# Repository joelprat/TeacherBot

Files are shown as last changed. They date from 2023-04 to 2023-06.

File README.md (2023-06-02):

# TeacherBot

# Table of Contents
  * [What is this?](#what-is-this)
  * [Physical Robot](#physical-robot)
  * [Hardware Scheme](#hardware-scheme)
  * [Software Scheme](#software-scheme)
  * [Requirements](#requirements)
  * [How to use](#how-to-use)
  * [TeacherBot DEMO](#teacherbot-demo)
  * [Authors](#authors)

# What is this?

This project consists of the design and construction of a robot capable of helping you to improve your knowledge of Catalan. It is able to understand and highlight syntax errors. 

It uses different electronic components, such as an Arduino board, stepper motors, motor controllers, a Bluetooth module and a servo motor. In addition, it uses the microphone and speaker of a mobile device to generate a human-robot interaction that provides a more dynamic experience. The physical implementation of the robot includes a metal structure and a robotic arm. 

This Catalan teaching robot is a great tool for anyone who wants to improve their Catalan language skills, whether to learn the language for academic or professional purposes, or just for fun. It is easy to use and very effective, which means that you will be able to significantly improve your level of Catalan in a very short time.

# Physical Robot
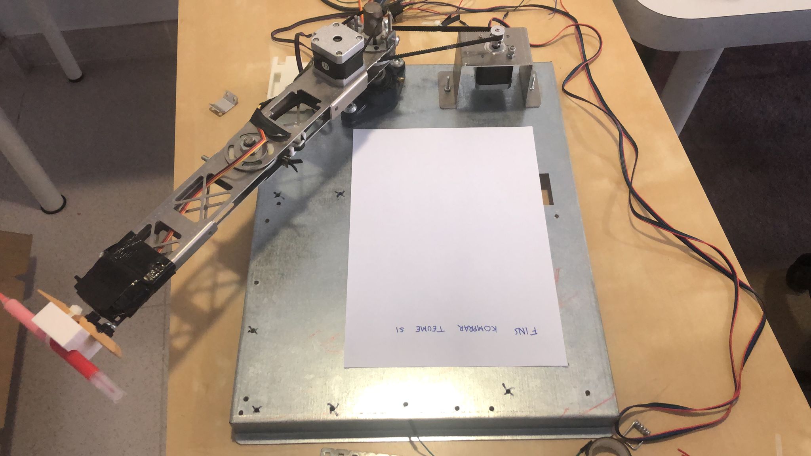
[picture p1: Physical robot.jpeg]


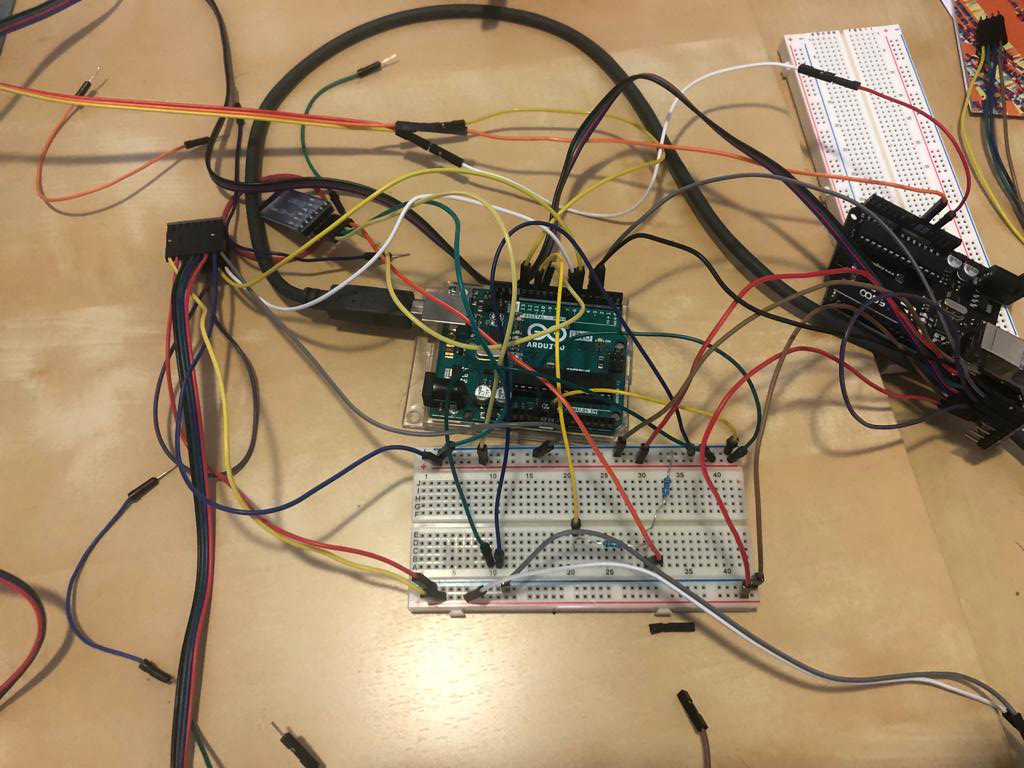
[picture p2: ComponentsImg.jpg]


# Hardware Scheme
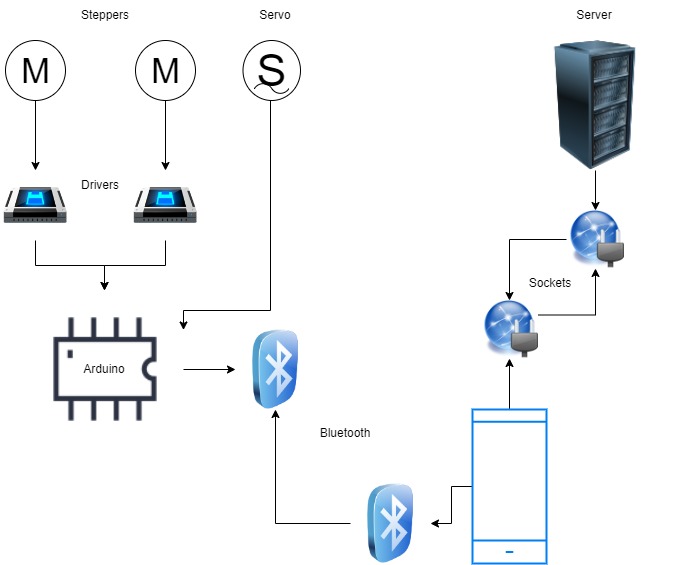
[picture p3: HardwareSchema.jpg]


# Software Scheme
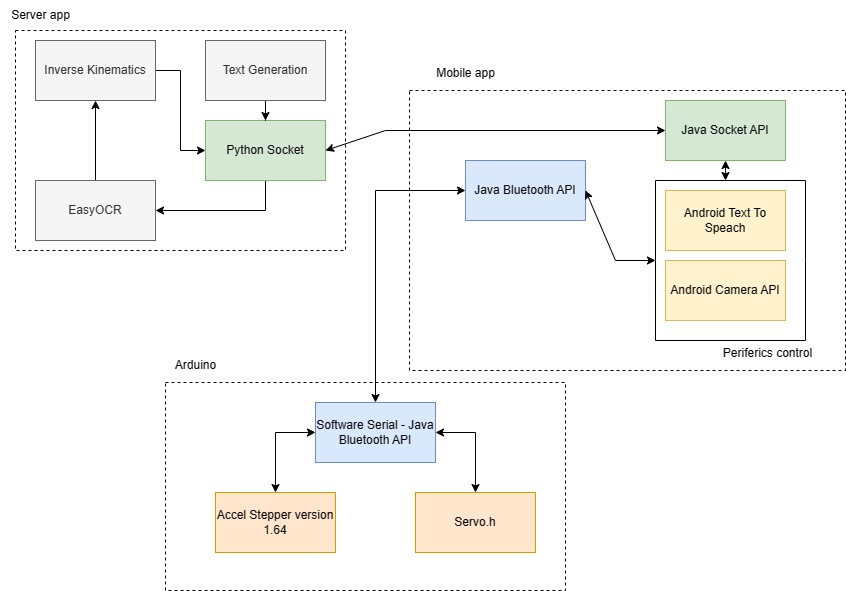
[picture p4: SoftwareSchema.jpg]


# Requirements

Python
 - [Python 3.11.x](https://www.python.org/)
 - [NumPy](https://numpy.org/)
 - [Sympy](https://www.sympy.org/)
 - [sympy.physics.mechanics](https://docs.sympy.org/latest/modules/physics/mechanics/index.html)
 - [requests](https://pypi.org/project/requests/)
 - [easyOCR](https://pypi.org/project/easyocr/)
 - [cv2](https://pypi.org/project/opencv-python/)
 - [socket](https://docs.python.org/3/library/socket.html)
 - [base64](https://docs.python.org/es/3/library/base64.html)
 - [translate](https://pypi.org/project/translate/)
 - [gTTs](https://pypi.org/project/gTTS/)
 - [pillow](https://pypi.org/project/Pillow/)
 - [faker](https://pypi.org/project/Faker/0.7.4/)

[Android Studio JDK](https://developer.android.com/studio):
 - SDK min 24 target 33
 - Java version 1.8
 - Java Bluetooth API
 - Java Socket API
 - Android Text To Speach
 - Android Camera API

[Arduino](https://support.arduino.cc/hc/en-us/articles/360019833020-Download-and-install-Arduino-IDE):
 - Accel Stepper version 1.64 (to be installed in arduino IDE)
 - Software Serial ((included in arduino IDE))
 - Servo.h (included in arduino IDE)
 - String.h (included in arduino IDE)

# How to use

1. Install Python.

2. Clone this repo.

    ```
    $ git clone https://github.com/joelprat/TeacherBot.git
    ```
    
3. Install the required libraries.

   If using Windows:
   
     ```
     $ cd \TeacherBot\algorithms\OCR\
     $ install_dependencies_windows.bat
     ```
     
   If using bash:
   
    ```
    $ cd /TeacherBot/algorithms/OCR/
    $ chmod +x install_dependencies_bash.sh
    $ ./install_dependencies_bash.sh
    ```

4.  Server execution.

    ```
    $ python server.py
    ```

# TeacherBot DEMO

(https://www.youtube.com/watch?v=jaYQ3ElwnmU)

# Authors

- [Contributors](https://github.com/joelprat/TeacherBot/graphs/contributors)

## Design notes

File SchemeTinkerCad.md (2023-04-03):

# Esquema



# Descripción
El diseño del circuito que hemos realizado está compuesto por los siguientes componentes: 
- Una placa arduino UNO R3
- Una placa de pruebas
- Un microservomotor
- Una pantalla LCD 16x2
- Dos motores CC con codificador
- Una controladora de motor (Pololu en el caso de tinkercad debido a la ausencia de nuestra específica controladora de motor). 
- Una pila (Únicamente utilizado para dar funcionamiento en el tinkercad, en nuestro sistema proporcionaremos la potencia por USB).

Otros componentes que no se ven representados en el diseño del circuito ,debido a que no aparecen en la herramienta de tinkercad, són los siguientes: 
- Un altavoz.
- Un microfono.
- Un dispositivo movil para la recaptación de la información a traves de fotografía.
- Un controlador WiFi.
- Un regulador de voltaje para el motor NEMA.

A pesar de no utilizar estos componentes en el diseño realizado, proporcionamos los módulos software para cada uno de los componentes, independientemente de si se encuentran en tinkercad o no, para hacerlos funcionar.

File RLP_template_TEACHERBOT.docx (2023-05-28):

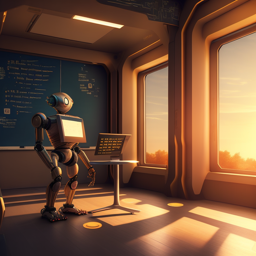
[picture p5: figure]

# TEACHERBOT

TEACHERBOT is a Catalan teacher who will correct texts written by you or dictated by the robot itself.

PROJECT SPRINT #2.
DATE: 03 May 2017

Carles Costas Mateu
Marc Cives Trillo
Joel Prat Vilanova
Eric Caballer Jiménez

TEACHERBOT

TEACHERBOT is a Catalan teacher who will correct texts written by you or dictated by the robot itself.

# Project description

This robot is a Catalan teacher designed to help you improve your Catalan skills. It is able to understand and highlight syntax errors with great accuracy.

This Catalan teacher robot not only corrects your written texts, but also gives you feedback on your mistakes using a screen, to help you understand why you made the mistake and how to avoid it in the future. Also, it can spell you a brief text in order to write it by yourself and then the robot will correct the mistakes that you have done.

This Catalan teaching robot is an excellent tool for anyone who wants to improve their Catalan skills, whether they are learning the language for academic or professional purposes, or just for fun. It's easy to use and very effective, which means you'll be able to significantly improve your Catalan level in no time.

# Electronic components

This is the list of the proposed components:

- 1 x ARDUINO UNO REV.3
- 1 x PROTOBOARD
- 2 x STEPPER MOTOR
- 1 x SERVOMOTOR
- 1 x MICROPHONE
- 1 x SPEAKER
- 1 x WIFI-MODULE
- 1 x ENGINE CONTROLLER
- 1 x VOLTAGE REGULATOR
- 1 x LCD SCREEN

# Hardware Scheme (optional, in case that you already had this ready)

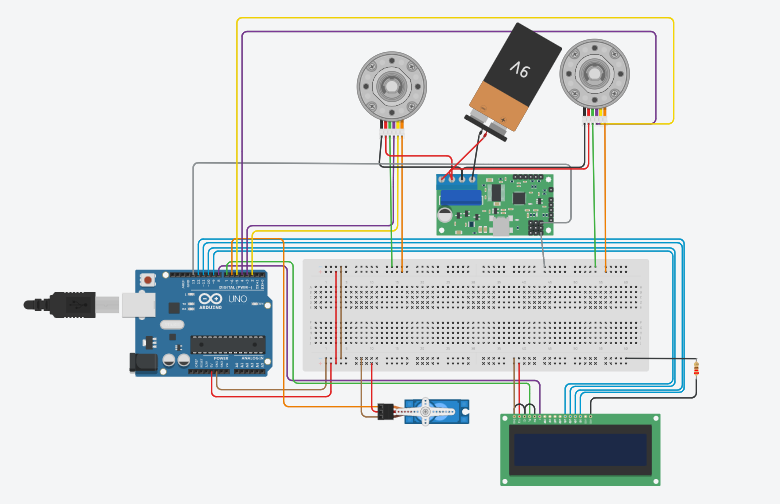
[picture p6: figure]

# Software Architecture (COMPULSORY)

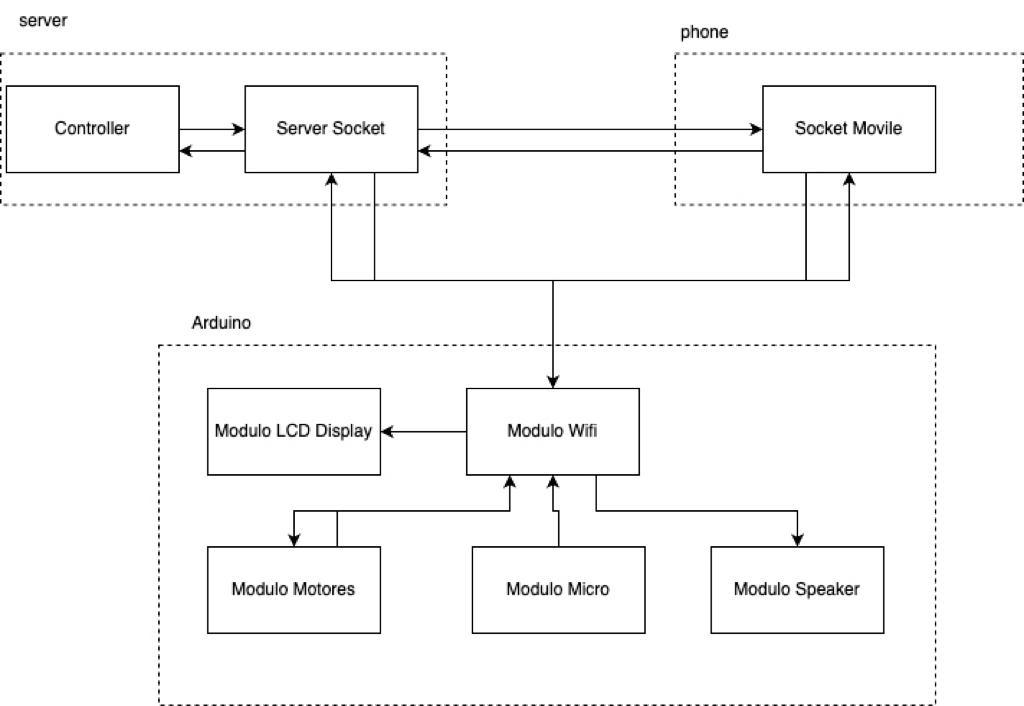
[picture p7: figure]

2) In the diagram, there are three different blocks that correspond to different systems, including the server, the phone, and the Arduino board.  Within the server, there is a block that is responsible for all the logic to compute the OCR and interpret the human speech, as well as generate the sound to be played by the speaker. This module will communicate via UDP socket.  Secondly, we have the phone, where we should have only one socket to receive the order to take photos and send these photos to the central server.  Finally, on the Arduino we have the WiFi module that will communicate with the sockets via UDP to send information from its peripherals or receive information that some of its peripherals need to use.

# Amazing contributions (COMPULSORY)

1. Special focus on Catalan: The robot has been specially designed for learning and improving the Catalan language. This makes it a highly specialized and effective tool for anyone who wants to improve their Catalan language skills.
2. Text correction capability: The robot is able to highlight mistakes in Catalan with great precision. This includes the correction of syntax errors, which helps to improve the text quality and, ultimately, the language skills.
3. Instant feedback: The robot not only corrects errors, but also provides feedback on the errors made so that users understand the error and know how to avoid it in the future. This helps to improve language skills effectively and efficiently.
4. Advanced technology: The robot is based on advanced natural language processing technology that allows it to understand and produce Catalan texts with great precision and coherence. This makes it an extremely effective tool for improving language skills in Catalan.

In case of fulfilling all the objectives our mark should be a 9 out of 10 because it always can be better. We think that we cover various aspects of engineering, both software and hardware, including machine learning with OCR, human language recognition, network communication protocols, and the use of various peripherals such as motors, LED screens, microphones, loudspeakers, etc.

We are working on the development of a new technology, we deal with the Catalan language and try to give an educational value to the project and integrate it with the Catalan culture. Also, it could be a reproducible and scalable project for different aspects in the educational field.

# Extra components and 3D pieces (COMPULSORY only a number of them, not all of them are compulsory in this sprint)

- 1 x PAPER HOLDER
- 1 x MOTOR SUPPORT
- 2 x MOTOR ARM
- 1 x MOBILE PHONE HOLDER
- 2 x NEMA MOTOR
- 1 x PENCIL HOLDER

PAPER HOLDER: It is used to hold the paper in which the robot will write.

MOTOR SUPPORT: It is used to hold the NEMA motors.

MOTOR ARM: Arm used to write on the sheet, by crossing out the word.

MOBILE PHONE HOLDER: Support in charge of holding the mobile to take photos.

NEMA MOTOR: In charge of moving the motor arms.

PENCIL HOLDER: Support in charge of holding the pencil.

We have a structure with a metal base where we place the paper support. The robotic arm consisting of a base 9.5 cm high and two arms 20 cm long each. At the end we put a servo motor to control the movement of the pen. This robot allows us a wide work space which we will only use a part corresponding to a DIN A4 sheet.

PAPER HOLDER:

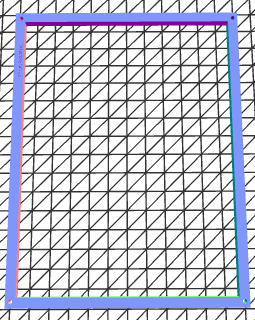
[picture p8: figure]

MOTOR SUPPORT:

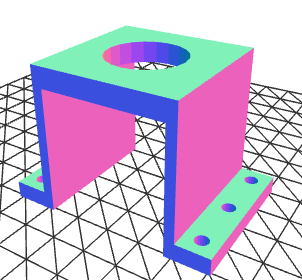
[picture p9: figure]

MOTOR ARM:

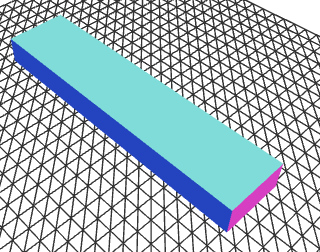
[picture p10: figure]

MOBILE PHONE HOLDER:

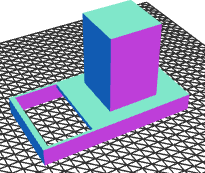
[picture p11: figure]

PENCIL HOLDER:

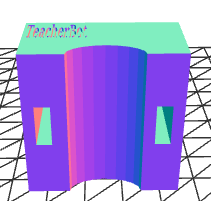
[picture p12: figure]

# Strategy for validation, testing and simulation (COMPULSORY, only the strategy, you do not need the tests to be done yet at this stage)

Functional tests: Functional tests can be performed to verify that the robot is performing its assigned tasks. For example, it can be tested whether the robot is able to accurately detect syntax errors in the Catalan language and provide feedback on the errors.

Integration tests: With these tests we ensure that all parts of the robot work together correctly. For example, we can check that the server communicates correctly with the phone and the Arduino board.

Performance tests: Performance tests can be performed to verify that the robot is working properly and efficiently. For example, it can be checked whether the robot is able to detect a syntax error in a reasonable time and provide feedback.

User evaluation: User tests can be performed to provide feedback on the effectiveness and usability of the robot. This can help identify areas for improvement and make adjustments to better meet user needs.

Risk # | Description | Probability (High/Medium/Low) | Impact (High/Medium/Low) | Contingency plan
1 | Bad recognition of text using OCR | M | H | None
2 | Incompatibility of Catalan with some libraries | M | H | Change the language
3 | Shock of the robotic arm with the support of the mobile support | L | H | Change the structure
4 | Failure with Wifi controller communication | M | H | Use Bluetooth instead
5 | Failure with Bluetooth communication | M | H | None

# Foreseen risks and contingency plan

References

This project has been inspired by the following Internet projects:

AINA: https://www.csuc.cat/es/noticia/aina-el-proyecto-para-que-la-tecnologia-entienda-y-hable-el-catalan

TOURING DRAWING: https://rlpengineeringschooluab2017.wordpress.com/2017/05/30/turing-drawing/

RPL - Computer Engineering. UAB (Barcelona) 2019-2020

Sprint #2 Date: 15 April 2020

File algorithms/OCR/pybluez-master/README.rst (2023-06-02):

==================
 PyBluez
==================

Python extension module allowing access to system Bluetooth resources.

https://github.com/karulis/pybluez

**EXAMPLES:**

.. code-block:: python

    # simple inquiry example
    import bluetooth
    
    nearby_devices = bluetooth.discover_devices(lookup_names=True)
    print("found %d devices" % len(nearby_devices))
    
    for addr, name in nearby_devices:
        print("  %s - %s" % (addr, name))

.. code-block:: python

    # bluetooth low energy scan
    from bluetooth.ble import DiscoveryService

    service = DiscoveryService()
    devices = service.discover(2)

    for address, name in devices.items():
        print("name: {}, address: {}".format(name, address))

*GNU/Linux and Windows XP examples:*

- `examples/simple/inquiry.py`_ - Detecting nearby Bluetooth devices
- `examples/simple/sdp-browse.py`_ - Browsing SDP services on a Bluetooth device.
- `examples/simple/rfcomm-server.py`_ - establishing an RFCOMM connection.
- `examples/simple/rfcomm-client.py`_ - establishing an RFCOMM connection.
- `examples/advanced/read-local-bdaddr.py`_ - provides the local Bluetooth device address.

*GNU/Linux only examples:*

- `examples/simple/l2capserver.py`_
- `examples/simple/l2capclient.py`_
- `examples/simple/asynchronous-inquiry.py`_

- `examples/bluezchat`_
- `examples/advanced/inquiry-with-rssi.py`_
- `examples/advanced/l2-unreliable-server.py`_
- `examples/advanced/l2-unreliable-client.py`_

*GNU/Linux experimental BLE support:*

- `examples/ble/scan.py`_
- `examples/ble/beacon.py`_
- `examples/ble/beacon_scan.py`_
- `examples/ble/read_name.py`_

**CONTACT:**

Please use the mailing list at
    http://groups.google.com/group/pybluez/

**INSTALLATION:**

Use pip(there are also binaries for Windows platform on PyPi):
    
    pip install pybluez

For experimental Bluetooth Low Energy support(only for Linux platform - for additional dependencies please take look at: `ble-dependencies`_):

    pip install pybluez[ble]

For source installation:

    python setup.py install

for Bluetooth Low Energy support:

    pip install -e .[ble]

**BUILD REQUIREMENTS:**

*GNU/Linux:*
 
- Python 2.3 or more recent version
- Python distutils (standard in most Python distros, separate package python-dev in Debian)
- BlueZ libraries and header files

*Windows:*

- Microsoft Windows XP SP1 or Windows Vista/7/8/8.1
- Visual C++ 2010 Express for build for Python 3.3 or newer 
- Visual C++ 2008 Express for build for Python 3.2 or older
- In order to build 64-bit debug and release executables, Visual Studio 2008/2010 Standard Edition is required
- Widcomm BTW development kit 5.0 or later (Optional)
- Python 2.3 or more recent version

*Mac OS X (Unstable - tested only on OS X 10.10/10.11)*:

- Python 2.3 or later
- Xcode
- PyObjc 3.1b or later (https://pythonhosted.org/pyobjc/install.html#manual-installation)

**LICENSE:**

  PyBluez is free software; you can redistribute it and/or modify it under the
  terms of the GNU General Public License as published by the Free Software
  Foundation; either version 2 of the License, or (at your option) any later
  version.
  
  PyBluez is distributed in the hope that it will be useful, but WITHOUT ANY
  WARRANTY; without even the implied warranty of MERCHANTABILITY or FITNESS FOR
  A PARTICULAR PURPOSE. See the GNU General Public License for more details.
  
  You should have received a copy of the GNU General Public License along with
  PyBluez; if not, write to the Free Software Foundation, Inc., 51 Franklin St,
  Fifth Floor, Boston, MA  02110-1301  USA
  
.. _examples/simple/inquiry.py: https://github.com/karulis/pybluez/blob/master/examples/simple/inquiry.py
.. _examples/simple/sdp-browse.py: https://github.com/karulis/pybluez/blob/master/examples/simple/sdp-browse.py
.. _examples/simple/rfcomm-server.py: https://github.com/karulis/pybluez/blob/master/examples/simple/rfcomm-server.py
.. _examples/simple/rfcomm-client.py: https://github.com/karulis/pybluez/blob/master/examples/simple/rfcomm-client.py
.. _examples/advanced/read-local-bdaddr.py: https://github.com/karulis/pybluez/blob/master/examples/advanced/read-local-bdaddr.py

.. _examples/simple/l2capserver.py: https://github.com/karulis/pybluez/blob/master/examples/simple/l2capserver.py
.. _examples/simple/l2capclient.py: https://github.com/karulis/pybluez/blob/master/examples/simple/l2capclient.py
.. _examples/simple/asynchronous-inquiry.py: https://github.com/karulis/pybluez/blob/master/examples/simple/asynchronous-inquiry.py

.. _examples/bluezchat: https://github.com/karulis/pybluez/blob/master/examples/bluezchat
.. _examples/advanced/inquiry-with-rssi.py: https://github.com/karulis/pybluez/blob/master/examples/advanced/inquiry-with-rssi.py
.. _examples/advanced/l2-unreliable-server.py: https://github.com/karulis/pybluez/blob/master/examples/advanced/l2-unreliable-server.py
.. _examples/advanced/l2-unreliable-client.py: https://github.com/karulis/pybluez/blob/master/examples/advanced/l2-unreliable-client.py

.. _examples/ble/scan.py: https://github.com/karulis/pybluez/blob/master/examples/ble/scan.py
.. _examples/ble/beacon.py: https://github.com/karulis/pybluez/blob/master/examples/ble/beacon.py
.. _examples/ble/beacon_scan.py: https://github.com/karulis/pybluez/blob/master/examples/ble/beacon_scan.py
.. _examples/ble/read_name.py: https://github.com/karulis/pybluez/blob/master/examples/ble/read_name.py

.. _ble-dependencies: https://bitbucket.org/OscarAcena/pygattlib/src/45e04060881a20189412681f52d55ff5add9f388/DEPENDS?at=default

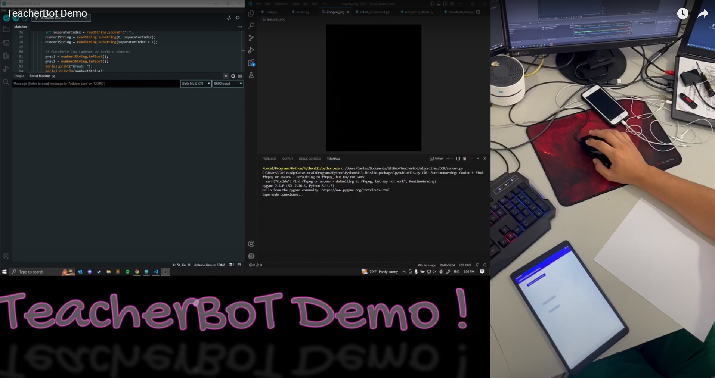
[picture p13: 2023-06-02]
demo.png

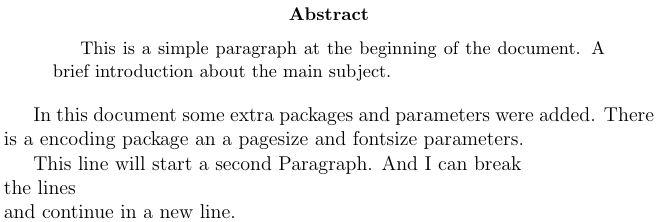
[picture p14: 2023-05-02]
algorithms/OCR/text.png

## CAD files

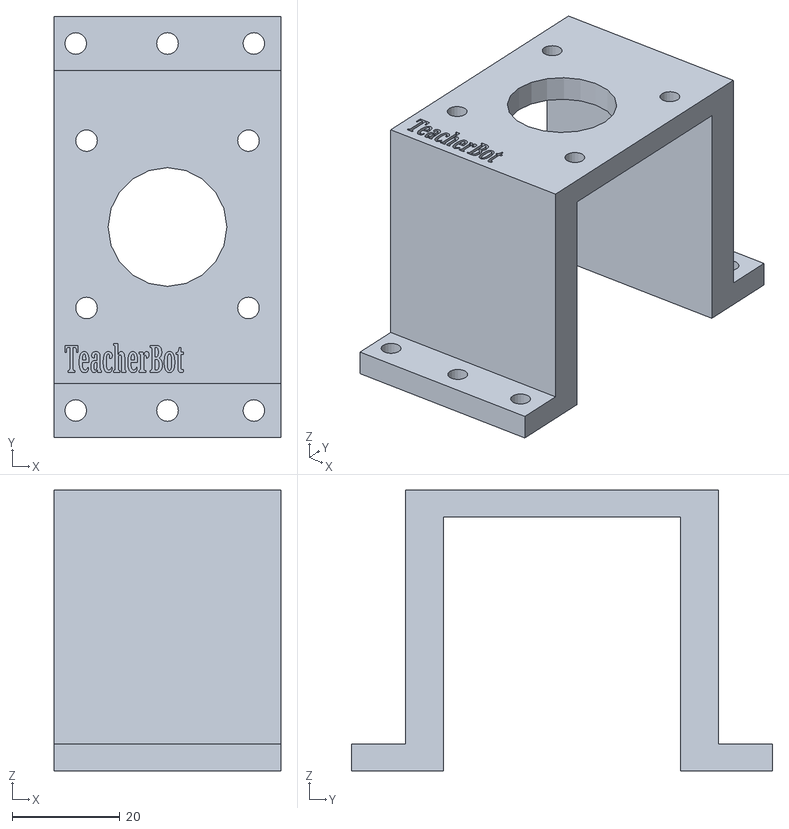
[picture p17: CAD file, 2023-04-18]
3D_pieces/Suport pel motor.stl
42.0 x 78.0 x 52.0

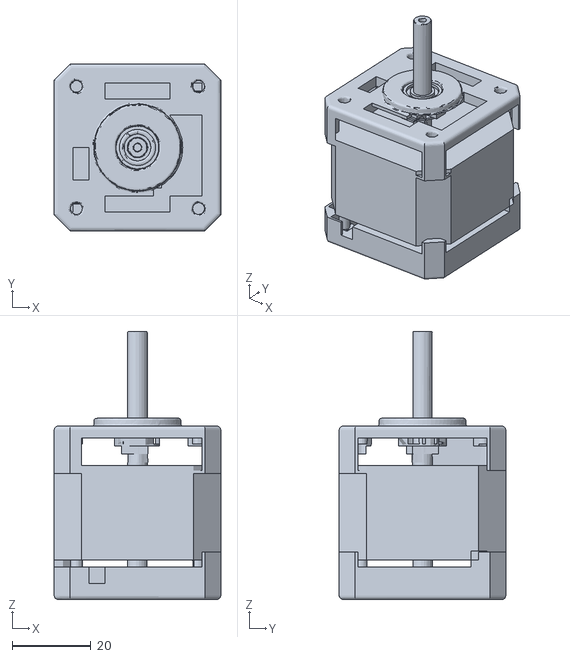
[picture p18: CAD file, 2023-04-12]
3D_pieces/NEMA 17.stl
42.3 x 42.3 x 68.0

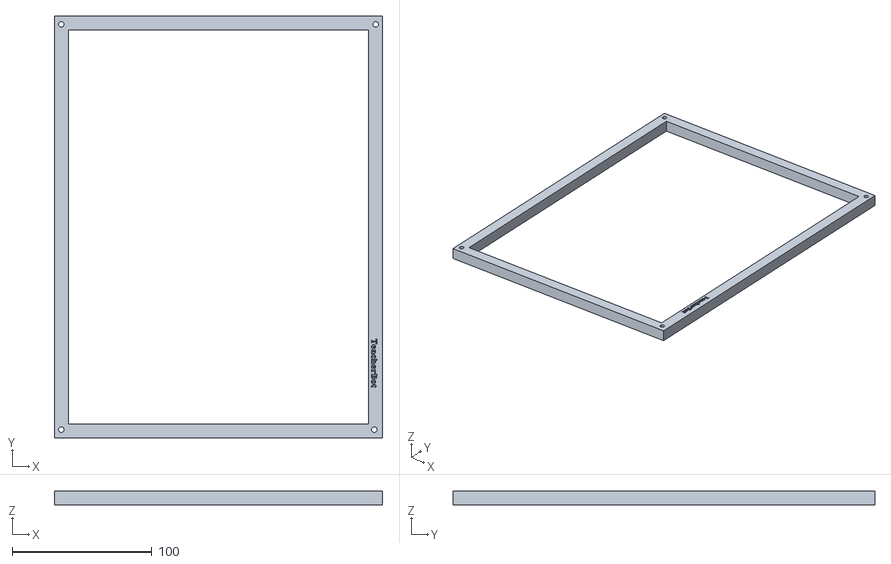
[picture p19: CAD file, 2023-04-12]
3D_pieces/Base.stl
235.0 x 302.0 x 10.0

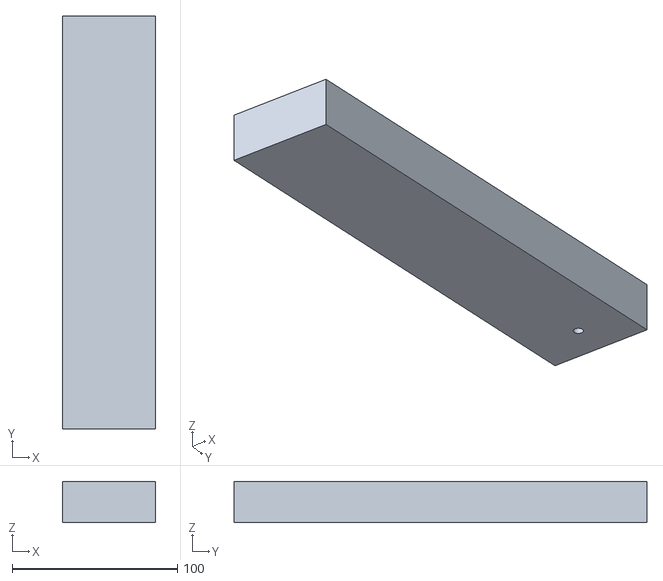
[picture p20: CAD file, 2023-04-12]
3D_pieces/Braç motor.stl
56.0 x 250.0 x 25.0

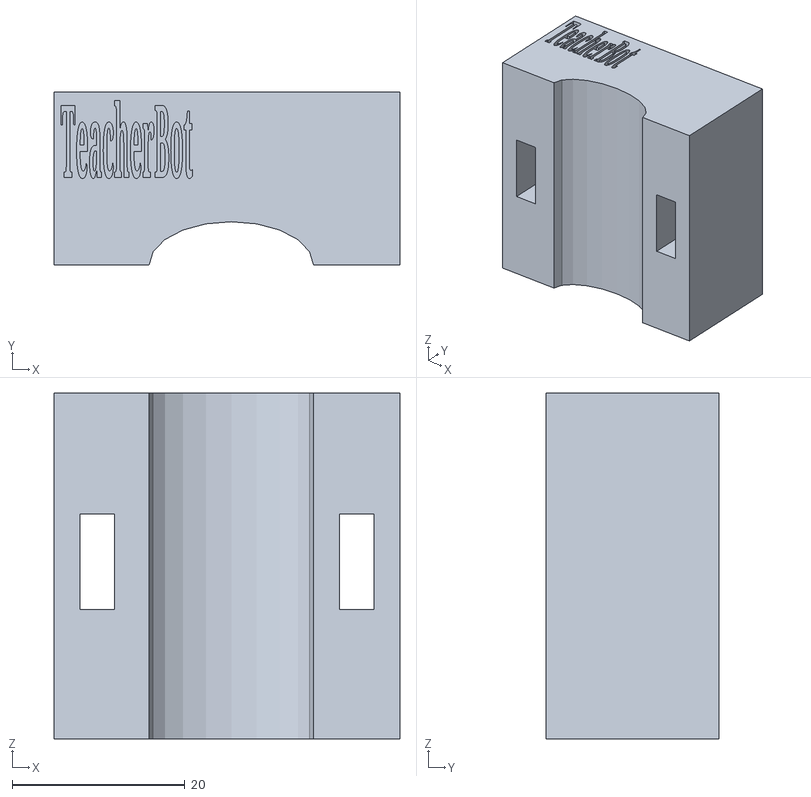
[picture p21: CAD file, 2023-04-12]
3D_pieces/Peça suport pel llapiç.stl
40.0 x 20.0 x 40.0

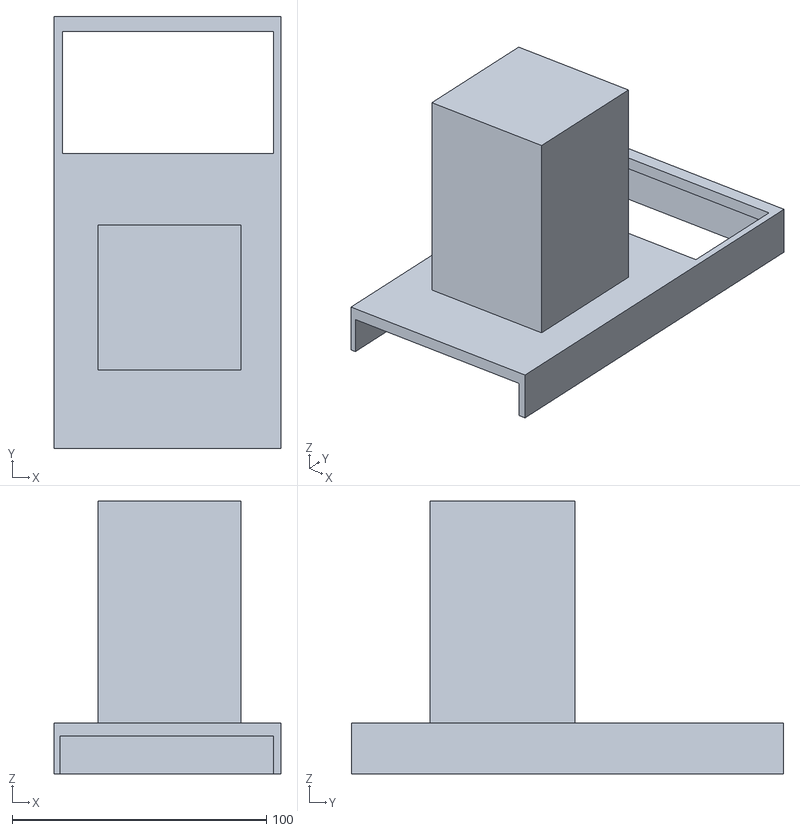
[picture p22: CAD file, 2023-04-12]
3D_pieces/Aguantamovil.stl
89.2 x 170.0 x 107.4

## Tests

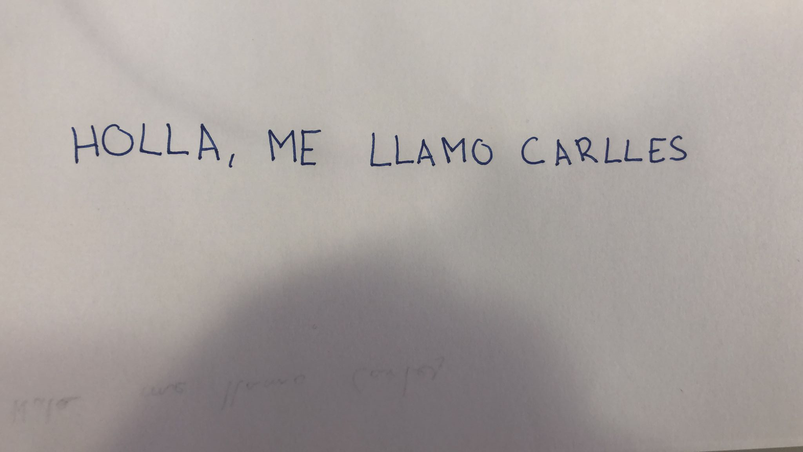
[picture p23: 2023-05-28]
algorithms/OCR/test1.jpeg

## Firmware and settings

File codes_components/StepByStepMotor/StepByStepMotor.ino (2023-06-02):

#include <AccelStepper.h>
// Configuración de pines
const int stepPin = 6;     // Pin STEP conectado al pin 6 del Arduino
const int dirPin = 7;      // Pin DIR conectado al pin 7 del Arduino
const int stepPin2 = 3;     // Pin STEP conectado al pin 6 del Arduino
const int dirPin2 = 4; 
AccelStepper stepper(AccelStepper::DRIVER, stepPin, dirPin);
AccelStepper stepper2(AccelStepper::DRIVER, stepPin2, dirPin2);

// Incluir la librería de la biblioteca Servo
#include <Servo.h>

// Crear un objeto de tipo Servo
Servo myservo;
void setup() {
  // Configurar los pines como salidas
  pinMode(stepPin, OUTPUT);
  pinMode(dirPin, OUTPUT);
  pinMode(stepPin2, OUTPUT);
  pinMode(dirPin2, OUTPUT);
  myservo.attach(13);
  stepper.setMaxSpeed(50);         // Velocidad máxima en pasos por segundo
  stepper.setAcceleration(50);      // Aceleración en pasos por segundo por segundo
  //stepper.setSpeed(500);             // Velocidad inicial en pasos por segundo
  stepper2.setMaxSpeed(100);         // Velocidad máxima en pasos por segundo
  stepper2.setAcceleration(100);
  int grau1 = 20;
  int grau2 = 90;
  int pasosObjetivo = grau1 * 800.0 / 360.0;
  int pasosObjetivo2 = grau2 * 800.0 / 360.0;
  //if(grau1<0){stepper.Direction(AccelStepper::DIRECTION_CW)}else{stepper.Direction(AccelStepper::DIRECTION_CCW)}
  //if(grau2<0){stepper2.Direction(AccelStepper::DIRECTION_CW)}else{stepper2.Direction(AccelStepper::DIRECTION_CCW)}
 // stepper.moveTo(pasosObjetivo);
  //stepper2.moveTo(pasosObjetivo2);
   myservo.write(0);
  int pasosMotor1[6] = {90};
  int pasosMotor2[6] = {0};
   for (int i = 0; i < 6; i++) {
      
      int pasosObjetivo = pasosMotor1[i] * 800.0 / 360.0;
      int pasosObjetivo2 = -pasosMotor2[i] * 800.0 / 360.0;
      
      stepper.moveTo(pasosObjetivo);
      stepper.runToPosition();
      
      // Mover el motor 2
      stepper2.moveTo(pasosObjetivo2);
      stepper2.runToPosition();
       while(stepper.distanceToGo() != 0 || stepper2.distanceToGo() != 0 ){
        if(stepper.distanceToGo() != 0 ){
          stepper.run();
        }
        if(stepper2.distanceToGo() != 0 ){
          stepper2.run();
        }          
       }
       delay(1000);
     if(i == 0 || i == 3){
          myservo.write(50);
        }
      if(i == 2 || i ==4){
        myservo.write(0);
      }
   //myservo.write(50);
   
  
    }
     myservo.write(0);
 
}

void loop() {

  
  digitalWrite(dirPin, HIGH);  // Invertir la dirección del giro
  
  
    /*
    // Mover el motor 1
    for (int i = 0; i < 2; i++) {
      
      int pasosObjetivo = pasosMotor1[i] * 800.0 / 360.0;
      int pasosObjetivo2 = pasosMotor2[i] * 800.0 / 360.0;
      stepper.moveTo(pasosObjetivo);
      stepper.runToPosition();

      // Mover el motor 2
      stepper2.moveTo(pasosObjetivo2);
      stepper2.runToPosition();
       while(stepper.distanceToGo() != 0 || stepper2.distanceToGo() != 0 ){
        if(stepper.distanceToGo() != 0 ){
          stepper.run();
        }
        if(stepper2.distanceToGo() != 0 ){
          stepper2.run();
        }          
       }
       delay(1000);
   //myservo.write(50);
   
   myservo.write(0);
    }
   */
  
  /*stepper.moveTo(100);  // Número de pasos a mover
  stepper.runToPosition();
  delay(1000);*/
 // delay(1000);  // Retardo de 1 segundo antes de repetir el ciclo
}

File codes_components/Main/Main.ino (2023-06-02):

#include <SoftwareSerial.h>
#include <AccelStepper.h>
#include <String.h>
// Incluir la librería de la biblioteca Servo
#include <Servo.h>

// Crear un objeto de tipo Servo
Servo myservo;
const int ledPin = 13;
int incomingByte = 0;
const int stepPin = 6;     // Pin STEP conectado al pin 6 del Arduino
const int dirPin = 7;      // Pin DIR conectado al pin 7 del Arduino
const int stepPin2 = 3;     // Pin STEP conectado al pin 6 del Arduino
const int dirPin2 = 4; 
int start = 0;
float grau1, grau2;
String readString ,number1String ,number2String;
SoftwareSerial BTSerial(10, 11);   // RX | TX
AccelStepper stepper(AccelStepper::DRIVER, stepPin, dirPin);
AccelStepper stepper2(AccelStepper::DRIVER, stepPin2, dirPin2);
void setup() {
  // Configurar los pines como salidas
myservo.attach(13);
myservo.write(0);
pinMode(stepPin, OUTPUT);
pinMode(dirPin, OUTPUT);
pinMode(stepPin2, OUTPUT);
pinMode(dirPin2, OUTPUT);
stepper.setMaxSpeed(100);         // Velocidad máxima en pasos por segundo
stepper.setAcceleration(100); 
stepper2.setMaxSpeed(100);         // Velocidad máxima en pasos por segundo
stepper2.setAcceleration(100);
Serial.begin(9600);
pinMode(ledPin, OUTPUT);
BTSerial.begin(9600);

}

void loop() {
  while (BTSerial.available()) {
     delay(2); //delay to allow byte to arrive in input buffer
      char c = BTSerial.read();
      if (c != '\n'){
       readString += c;
      }
    }
    BTSerial.flush();
    if (readString.length() > 0){
      
       Serial.print("Envio: ");
       Serial.println(readString);
      if(readString == "START"){
        start = 1;
        //readString = "";
       
        
        }
      if(readString == "END"){
        start = 0;
        //readString = "";
        }
        if(readString == "PING"){
         myservo.write(50);
        //readString = "";
        delay(500);
        }
        if(readString == "PONG"){
         myservo.write(0);
        //readString = "";
        delay(500);
        }
      if(start == 1 && readString != "START" && readString != "PING" &&  readString != "PONG"){ 
        digitalWrite(ledPin, HIGH);     
        digitalWrite(dirPin, HIGH);  // Invertir la dirección del giro

        int separatorIndex = readString.indexOf('|');
        number1String = readString.substring(0, separatorIndex);
        number2String = readString.substring(separatorIndex + 1);
  
        // Convierte las cadenas de texto a números
        grau1 = number1String.toFloat();
        grau2 = number2String.toFloat();
        Serial.print("Grau1: ");
        Serial.println(number1String);
        Serial.print("Grau12 ");
        Serial.println(number2String);
        
        int pasosObjetivo1 = grau1 * 800 / 360.0;
        int pasosObjetivo2 = -grau2 * 800 / 360.0; 
        
        stepper.moveTo(pasosObjetivo1);
        stepper2.moveTo(pasosObjetivo2);
        while(stepper.distanceToGo() != 0 || stepper2.distanceToGo() != 0 ){
          if(stepper.distanceToGo() != 0 ){
            stepper.run();
          }
          if(stepper2.distanceToGo() != 0 ){
            stepper2.run();
          }          
        }
        delay(1000);
        
        
        readString = "";
        //delay(10000);  // Retardo de 1 segundo antes de repetir el ciclo
       }
        readString = "";
    }
   // delay(1000); //a little delay is needed so you can see the

}

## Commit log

2023-04-12 Peces 3D
    [Aguantamovil.stl, Braç motor.stl, Peça suport pel llapiç.stl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]
2023-04-12 Github refactor
    [Aguantamovil.stl, Braç motor.stl, Peça suport pel llapiç.stl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]
2023-04-12 Braç motor actualitzat
    [Braç motor.stl]
2023-04-12 pieces 3D
    [Base.stl, NEMA 17.stl]
2023-04-18 Suport pel motor actualitzat a nema 17
    [Suport pel motor.stl]
2023-05-02 algoritmo OCR con corrección de texto
2023-05-02 Actualización código
    Tener un diccionario con las palabras incorrectas junto a sus posiciones en la imagen, width y height
2023-05-20 Word Generator Server
    New functions added in main to generate words and sentences
    New file created with the logic of socket server
    New File with arduino code to control HC-06 module
2023-05-28 App and Improvments in Arduino and Main Server
